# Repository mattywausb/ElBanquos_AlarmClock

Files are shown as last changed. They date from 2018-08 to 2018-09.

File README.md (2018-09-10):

# ElBanquos_AlarmClock
An Arduino based radio alarm clock with a unique display method and an efficient user interface
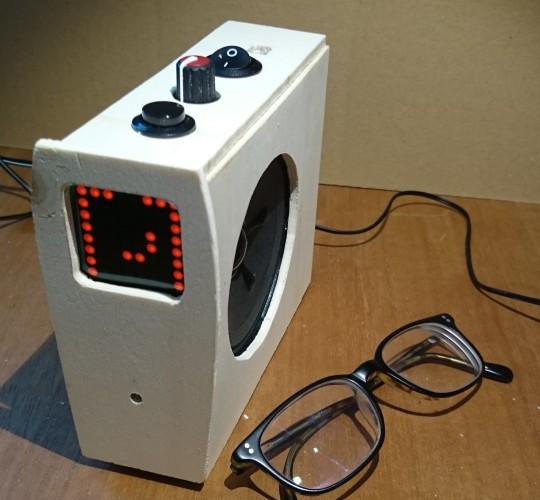
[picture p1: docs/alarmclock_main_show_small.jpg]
Overview Picture The clock and my glasses


* [Bedienungsanleitung (German Manual)](https://mattywausb.github.io/ElBanquos_AlarmClock/docs/manual-de.html)
* [Manual](https://mattywausb.github.io/ElBanquos_AlarmClock/docs/manual-en.html)

# Introduction
Actual alarm clocks are often not designed very well, because they try to be cheap and very multifunctional.
I want to create an alarm clock, that is optimized by enhanceing the essential features an reducing all gimmicks not necessary for the job.

Essential functions of a radio alarm clock
* show the actual time (in a good adapted brightness)
* Play radio to wake me up (fading it smothly in)
* efficient and reliable change of alarm time
* ensure correct volume of sound (minimize risk of silent alarm due to bad volume controller)
* Get correct time through available broadcast services (RDS is best, since we need a radio module anyway)
* Snooze function
* "Hard to Kill" alarm off procedure (Procedure needs more then just hitting a button)
* Switch bewteen alarm mode and non alarm mode
* stop bothering after (1?) Hour

Personal essential feature
* show time in a pattern, a short sighted person still can recognize over 2 meters 
* Nap function (Wake me up after a defined interval)

Nice to have functions
* Sleep function - Play Radio on demand for a defined time and fade it out smoothly

Further extentions
* Dim up light to simulate sunrise before starting the radio

Unecessary function
* Play radio for endless time
* Change radio stations (I always wake up with the same)
* Show Radio Station name
* shot weather and other data etc.

# Repository content
In the repository you will find all necessary code and diagrams to build the clock by yourself
* Arduino sketch including
** Display programming
** Encoder reading
** RDS Data cleansing procedure
** "EEPROM Database" class for easy storing data on EEPROM
* Fritzing circuit plan (not full PCB layout, since I just build on prototype boards)
** Also provided as png export
* Manuals and design approach
* Rough skecth to build a housing
* [List of Parts](https://mattywausb.github.io/ElBanquos_AlarmClock/docs/listofparts.html)

# Tools you need
* Arduino IDE
* Frizing
* inkscape (or some other svg tool to read the building sketches)

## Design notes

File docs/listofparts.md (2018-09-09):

This is hopefully the list of all parts I needed. For better orientation it is devided over multimple subassemblies

# Power supply and basic elements
* 9V regulated power plug (Main Power input)
* prototyping PCB board
* Wires, double wires and ribbon cables
* 2 port contact terminal or 9v power socket

# core processing elements 
(Needed to test the software)
* arduino nano
* SI 470x Radio Module
* 8x8 LED Matrix board with max7219 driver
* 5 wire connector cable
* photodiode
* 10 k Resistor
* encoder switch with button function
* button (Easy to hit)
* switch with tight movement
* cheap earphone (need just the cable with the plug as antenna an input to the amplifier)

# Audio amplifier 
(Needed to hear anything without earphone)
* lm7805 voltage regulator
* 100nf capacitor
* 470nf capacitor
* lm386 operations amplifier
* 20k potentionmeter
* 100nF capacitor
* 2x 100uF capacitor
* Speaker (8cm diameter)
* 2 port Contact terminal

# Housing 
(Needed, so you dont fall into your electronics at night)
* plywood 4-6mm of your favourite kind
* green light filter (to reduce overall brightness of the red led)
* Anything to hold everythin together (Scews, nuts, glue etc)

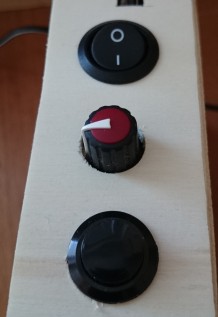
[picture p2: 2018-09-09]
docs/Buttons.jpg

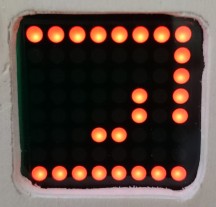
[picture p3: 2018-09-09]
docs/time04-30.jpg

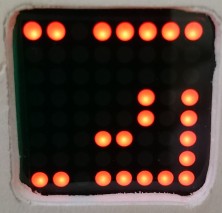
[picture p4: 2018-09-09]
docs/time02-30-almoff.jpg

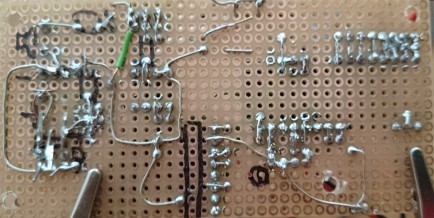
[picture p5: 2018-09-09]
docs/pcb_bottom_side.jpg

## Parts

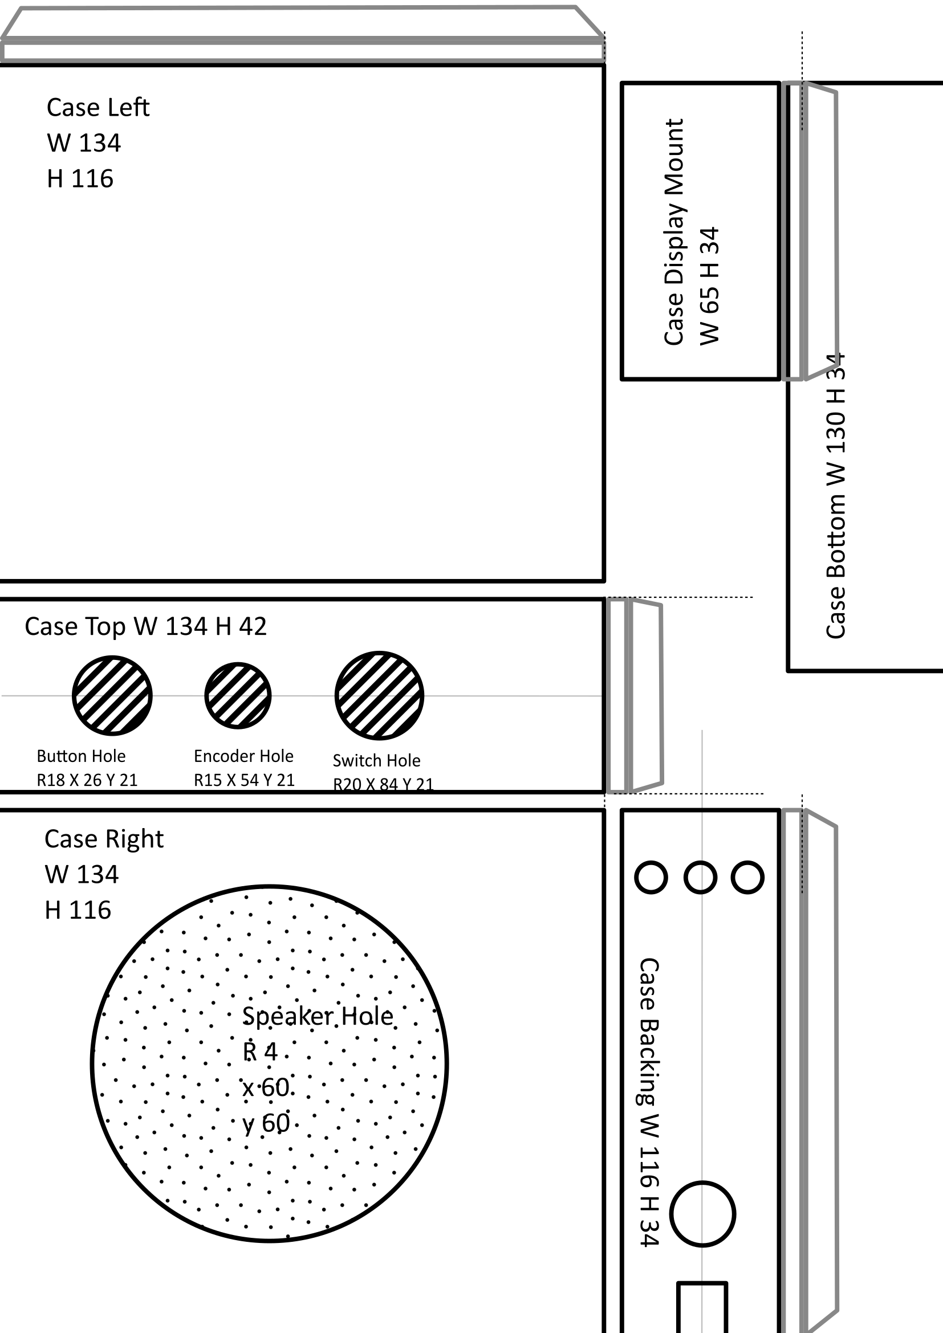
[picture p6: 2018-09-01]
docs/case parts cutting layout.png

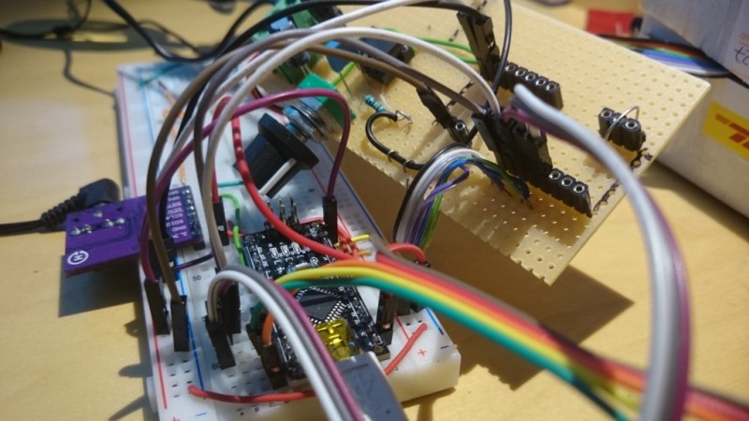
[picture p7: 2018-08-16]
docs/Digital_and_analog_parts.JPG

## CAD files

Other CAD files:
blender/model_mk2.blend

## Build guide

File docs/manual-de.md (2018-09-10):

# El Banquos Radiowecker - Bedienungsanleitung

Mangels eines ausgereiften Produktes in den hiesigen Elektronikmärkten habe ich mir einen eigenen Radiowecker gebaut,
der folgende Eigenschaften in sich vereint:

* Leicht einstellbare Weckzeit (Vor- und Zurückstellbar)
* "Einblenden" der Radiolautstärke zur Weckzeit (statt brachialem "Radio an")
* Eine Anzeige die ich auch ohne Brille(Kurzsichtig) ablesen kann, aber nicht gleich riesig ist
* "entspannte" Zeitanzeige (Ich brauche es nicht auf die Minute genau) 
* Anzeige ist nur so hell, wie gerade nötig und nicht mit geschlossenen Augen warnehmbar
* Stellt sich selbst mittels der im Radiosignal verfügbare Zeitinformation (RDS)
* Nickerchenfunktion (Radio an nach definiertem Interval (z.B. 20 Min für PowerNap)
* Deaktivieren des Alarms kann nicht aus Versehen passieren
* Sender und Lautstärke können nicht aus Versehen verstellt werden

# Bestandteile des Weckers
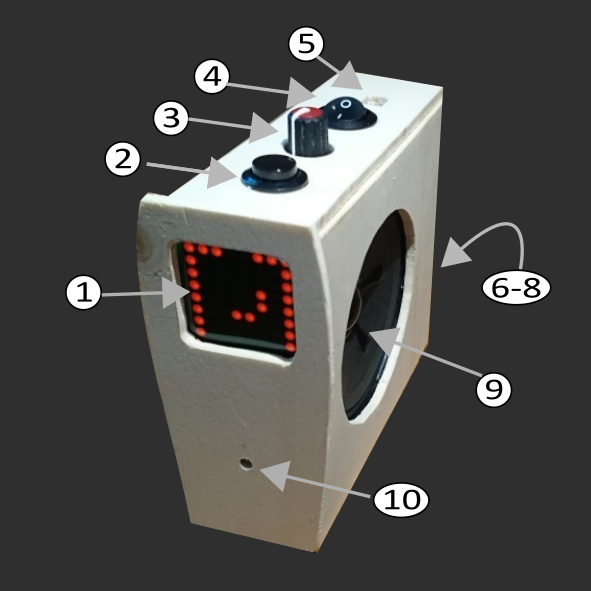
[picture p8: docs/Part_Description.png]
Bild Teilebezeichnung

1. 8x8 LED Punkmatrix Display zur Anzeige aller Informationen
2. Schlummer Taste
3. Drehregler und Taste Einstellung und Bestätigung verschiedener Funktionen
4. Weckfunktionschalter 
5. USB Port des Arduino für Softwareupdates
6. "Wurfantenne"
7. Lauststärkeregler
8. Kabelausgang zum Netzteil
9. Lautsprecher
10. Lichtsensor

# Inbetriebnahme und Schnellstart
1. Wecker an das Stromnetz anschließen -> Auf dem Display erscheit kurz ein "Bestätigungssymbol" und danach die "Zeitsuchanzeige". Der Wecker 
wartet nun auf Zeitinformationen im Radiosignal. Da diese nur 1 mal pro Minute gesendet werden und der Wecker
außerdem mindestens auf 10 plausible Werte waret, wird dieser Vorgang mindestens 10 Minuten dauern. Trotzdem kann jetzt schon die Weckzeit eingestellt werden
2. Einstellen der Weckzeit einleiten durch einmaliges Drücken auf den Drehschalter
3. Drehregler vor- oder zurückdrehen bis die gewünschte Weckzeit angezeigt wird (siehe gleich, lesen der Zeitanzeige)
4. Drehregler drücken um die gewählte Zeit als Weckzeit zu speichern -  Auf dem Display erscheit kurz ein "Bestätigungssymbol" 
und danach die Zeitanzeige bzw. die Zeitsuchanzeige
5. Weckfunktionschalter auf 1 stellen  -> In der Zeitanzeige wird der Status entsprechend angezeigt.

Der Wecker schaltete sich nun zu der gesetzten Uhrzeit ein.
* Um den Alarm für 10 Minuten zu pausieren, Schlummer Taste drücken -> Radio geht aus, Im Display blinken zwei Punkte. Das Radio schaltet sich nach 10 Minuten wieder an
* Um den Alarm abzustellen, den Drehregler drehen-> Auf dem Display wird mit der Drehbewegung ein Quadrat gezeichnet. 
Hat man weit geng gedreht um das Quadrat zu komplettieren, wird der Alarm beendet
* Um zu verhindern, das der Alarm am nächsten Tag erneut aktiv wird, muss der Alarmschalter auf 0 gestellt werden.

Hinweis: Ein aktiver Alarm wird durch abschalten des Weckfunktionschalters nicht beendet. Dazu ist die beschriebene Prozedur  mit dem Drehregler notnwedig
Alternativ schaltet sich das Radio nach 1 Stunde automatisch ab.

# Die Uhrzeitanzeige
Die Zeitanzeige wurde so gestaltet, dass sie in der Nacht auch von einem kurzsichtigen Menschen ohne Brille mit moderatem Abstand gelesen werden kann. 
Sie ist deshalb mit einfachen Linienmustern konzipiert, die für alle Zeiteinheiten gut differenzierbar sind. 

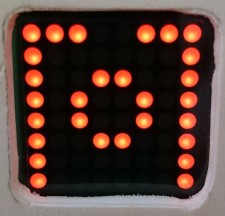
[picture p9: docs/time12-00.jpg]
time1200 12:00 Uhr


Die Anzeige teilt sich in zwei Elemente:
* Stundenrahmen (mit einer 1 Stunden und 3 Stunden Lücke)
* Viertelstundenkreis
Da die Zeit insgesamt mit einer Genauigkeit von nur 15 Minuten angezeigt wird, ist sie gegenüber der präzisen Zeit um 5 Minuten
vorversetzt, d.h. die volle Stunde wird 5 Minuten vor dem erreichen der vollen Stunde angezeigt. 
Der gleiche Versatz für alle weiteren Abschnitte der Stunde. (Dieser Verstatz gilt nur für die Echtzeitanzeige. Die Einstellung der Alarmzeit hat eine exakte Anzeige)
## Der Stundenrahmen
Der Stundenrahmen wird am äußeren Rand des Displays angezeigt. Eine kleine Lücke aus 2 Punkten zeigt die aktuelle Stunde an, analog wie bei einer Zeigeruhr (12 Uhr oben mittig, 3 uhr rechts mittig usw).

Ab 20 Minuten vor der Folgestunde rückt diese Lücke um ein Punkt vor, um die relative Nähe
zur kommenden Stunde anzuzeigen. 

Die Rahmenkante gegnüber der Stundenlücke wird komplett offen gelassen (große Lücke). Dadurch ist eine sehr grobe Einschätzung der Zeit ohne Erkennen der kleinen Lücke möglich. Gerade die allgemein "weckkrittischen" Stunden 5-7 Uhr sind damit gut von den davor liegenden Stunden 11-1 und 2-4 unterscheidbar.

Solange der Alarm über den Schalter **abgeschaltet** ist, wird dies durch **zwei Lücken** in den "seitlichen" Rahmenkanten erkennbar gemacht.
## Viertelstundenkreis
In der Mitte des Displays wird der Fortschritt innerhalb einer Stunde in 15 Minutenschritten angezeigt.
* -5 Minuten bis + 5 Minuten zur vollen Stunde: Voller kreis
* 5 Minuten- 10 Minuten: keine Markierung in der Mitte
* 10 - 25 Minuten: 2 Pixel rechts der Mitte
* 25-40 Minuten: zusätzlich 2 Pixel unterhalb der Mitte
* 40-55 Minuten: zusätzlich 2 Pixel links der Mitte
## Beispiele

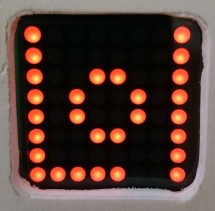
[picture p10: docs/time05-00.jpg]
display 05:00 Uhr
| 5:00 Uhr
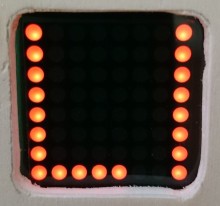
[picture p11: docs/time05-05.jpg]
display 05:05 Uhr
| 5:05 Uhr
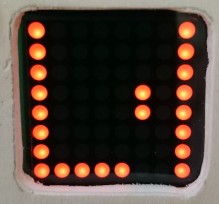
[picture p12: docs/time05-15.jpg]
display 05:15 Uhr
| 5:15 Uhr
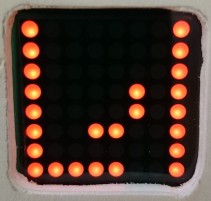
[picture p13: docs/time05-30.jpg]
display 05:30 Uhr
| 5:30 Uhr
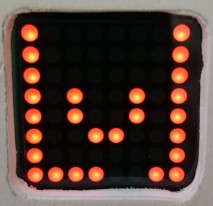
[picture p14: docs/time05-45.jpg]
display 05:45 Uhr
| 5:45 Uhr
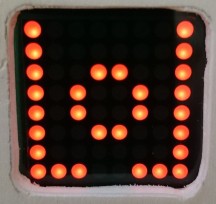
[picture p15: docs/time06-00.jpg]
display 06:00 Uhr
| 6:00 Uhr

# Die Weckzeitanzeige
Die Weckzeitanzeige ist ähnlich wie die Uhrzeitanzeige abzulesen. Es gibt folgende Unterschiede:
* Minuten werden in mit einem kleinen Quadreat(4x4) in der Mitte des Displays dargestellt. Jeder Punkt des Quardrates steht für 5 Minuten. Der volle Kreis steht für die volle Stunde.
* Uhrzeiten am Nachmittag und Abend  (12-23 Uhr) werden durch einen ausgefüllten Mittelpunkt der Anzeige kenntlich gemacht.
* Die sonst offene Kante des Stundenrahmens ist geschlossen (Anzeige der Weckzeit) oder blinkt (Einstellung der Weckzeit)
* Die angezeigte Zeit entspricht exakt dem Wert, der gerade gewählt wurde.
## Beispiele
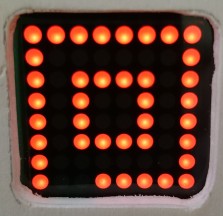
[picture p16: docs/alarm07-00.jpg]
display 07:00 Uhr
| 7:00 Uhr
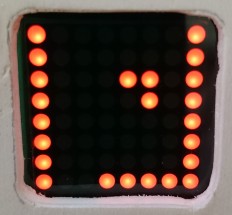
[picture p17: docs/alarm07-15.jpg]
display 07:15 Uhr
| 7:15 Uhr
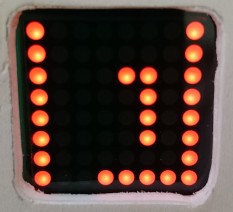
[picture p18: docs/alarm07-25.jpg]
display 07:25 Uhr
| 7:25 Uhr
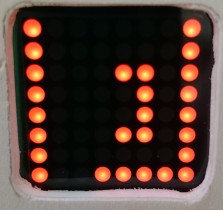
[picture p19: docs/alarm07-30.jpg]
display 07:30 Uhr
| 7:30 Uhr

# Bedienung

## Weckzeit anzeigen
Wenn sich das der Wecker im Ruhezustand befindet (Anzeige der Uhrzeit, keine laufender Alarm) kann man sich die eingestellte Weckzeit wie folgt anzeigen lassen:
1. Drehregler drehen -> Die Weckzeit wird angezeigt, nach einer kurzen Wartezeit springt die anzeige selbständig zurück auf die Uhrzeit

Alternativ kann mit der Schlummer Taste unverzüglich auf die Uhrzeit zurückgeschaltet werden

## Weckzeit stellen
Wenn sich der Wecker im Ruhezustand befinden (Anzeige der Uhrzeit oder Weckzeit, kein laufender Alarm) kann die Weckzeit wie folgt eingestellt werden:
1. Drehregler drücken -> Die Weckzeit wird angezeigt, wobei die offene Kante des Stundenrahmens blinkt
2. Drehregler vor oder zurückdrehen bis die gewünschte Weckzeit angezeigt wird 
3. Drehregler drücken oder 10 Sekunden keine Bedienung vornehmen um die gewählte Zeit als Weckzeit festzulegen-->  Auf dem Display erscheint kurz ein "Bestätigungssymbol" und danach die Zeitanzeige bzw. die Zeitsuchanzeige

Alternativ kann mit dem Schlummer Taste die Änderung der Weckzeit abgebrochen werden.

## Weckfunktion ein/ausshalten
Die grundsätzliche Aktivierung der Weckfunktion erfolgt mit dem Weckfunktionschalter. Damit der Alarm bei Erreichen der Weckzeit aktiviert wird, muss dieser Schalter auf "1" gestellt sein. Ist er auf "0" gestellt und der Alarm damit deaktiviert, wird dies durch zwei kleine Lücken in den seitlichen Kanten des Stundenrahmens im Display angezeigt.
Alarm an: time1200 12:00 Uhr Alarm an
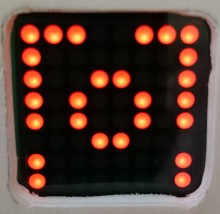
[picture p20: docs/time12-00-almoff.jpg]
time1200 12:00 Uhr Alarm aus
Alarm aus: 

**Hinweis:** Ein laufender Alarm wird durch das Auschalten nicht beendet.
Die "Nickerchen" Funktion arbeitet unabhängig von der Position des Alarmschalters.

## Alarm pausieren ("Schlummer")
Wenn das Radio aufgrund des erreichens der Alarmzeit eingeschaltet wurde, kann man den Alarm pausieren:
1. Schlummer Taste betätigen -> Das Radio wird abgeschaltet und nach 10 Minuten erneut aktiviert. Während der "Schlummerphase" blinken zwei Punkte in der offenen Kante der Uhrzeitanzeige.

## Aktuellen Alarm beenden
Um einen laufenden  oder pausierten Alarm zu beenden:
1. Drehregler drehen-> Auf dem Display erscheint Quadrat mit einem Mittelpunkt
2. Drehregler weiter drehen bis das Quadrat verschwunden ist -> der Alarm wird beendet
alm of procedure display Anzeige zum ausschalten des laufenden Alarms

## Nickerchenfunktion
Für ein Nickerchen, kann der Wecker unabhängig von der Weckzeit auf ein Intervall eingestellt werden, nach dem er dann die Weckfunktion aktiviert.
1. Schlummer Taste drücken -> Auf dem Display erscheint ein  "Minutenquadrat", voreingestellt auf 20 Minuten(=4 Punkte) (Be schon laufender Nickerchenfunktion wird die verbleibenden Restzeit angezeigt)
2. Mit dem Drehregler kann die Dauer in 5 Minutenschritten zwischen 0 und 120 Minuten(großes komplettes Quadrat) geändert werden 
3. Mit drücken auf den Drehregler (oder aber nach 10 Sekunden ohne Bedienhandlung) wird die gewählte Dauer bestätigen -> Bestätigtungshaken erscheint und danach die Uhrzeit wobei zwei Punkte in der offenen Kante des Stundenrahmens blinken

Der Wecker alarmiert nach Ablauf der eingestellten Zeit.

## Nickerchenfunktion ausschalten
Die Nickerchenfunktion ist im Grunde identisch mit der Schlummerfunktion. Entsprend wird sie auch genauso abgeschaltet 
1. Drehregler drehen-> Auf dem Display erscheint mit der Drehbewegung ein Quadrat 
2. Drehregler weiter drehen bis das Quadrat verschwunden ist ->  die Nickerchenfunktion wird abgeschaltet (der Alarm beendet)

## Einschlaffunktion / Radio an
Über die Schlaffunktion kann das Radio spontan für eine definierte Zeit eingeschaltet werden.
1. Schlummer Taste drücken --> Auf dem Display erscheint ein  "Minutenquadrat", voreingestellt auf 20 Minuten für ein Nickerchen
2. Mit dem Drehregler die Dauer verringern und über den Nullpunkt drehen-> das Radio schaltet sich ein.
3. Durch Weiterdrehen kann die Einschaltdauer in 5 Minutenschritten geändert werden 
4. Mit Drücken auf den Drehregler die gewählte Dauer bestätigen -> Das Radio wird sich nach Ablaufen der Dauer abschalten

Alternativ: Wird nach der Anpassung der Zeit keine weitere Bedienung vorgenommen, wird die angezeigte Zeit als Laufzeit übernommen

## Einschlaffunktion / Radio abschalten
Wenn das Radio über die Schlaffunktion aktiviert wurde, kann es wie folgt abgeschaltet werden:
1. Schlummer Taste drücken -> Auf dem Display erscheint das  "Minutenquadrat, mit der Restzeit der Schlaffunktion
2. Schlummer Taste drücken -> die Schlaffunktion wird abgeschaltet

Alternativ kann die Zeitdauer mit dem Drehregler auch wieder angepasst werden.

# Zeitsuchanzeige
Die Zeitinformation im RDS Signal ist störanfällig und bedarf einer längeren Prüfung bevor sie vertrauenswürdig ist. Die Zeitsuchanzeige wird angezeigt, solange der Wecker nach dem Einschalten keine zuverlässige Uhrzeitinformation besitzt.
Sie besteht aus folgenden Elementen:
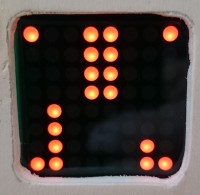
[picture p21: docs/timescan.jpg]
timescan Zeitsuchanzeige

* Linker Balken von unten nach oben: Empfangsstärke des laufenden Senders 
* Mittlerer Balken von oben nach unten: Vertrauen in den aktuell empfangenden RDS Wert (Wenn dieser Balken den unteren Displayrand erreicht, wurden genügen Informationen gesammelt um die Uhrzeit zu übernehmen) 
* Rechter Balken von unten nach oben: Vertrauen in die aktive Uhrzeit

Die Uhr übernimmt die aktuelle  RDS Uhrzeit nur dann, wenn sie das gleiche oder bessere Vertrauen in die RDS zeit als in die laufende Uhrzeit hat. Zu Sommer/Winterzeitumstellung werden 20 korrekte Messungen benötigt, bis die neue Uhrzeit in das System übernommen wird. Eine Weckzeit zwischen 3:00 und 3:20 in der Winterzeitumstellung wird daher nicht korrekt erkannt.

# Verhalten bei einem Neustart
Ein Neustart der Uhr erfolgt
* Nach einem Stromausfall
* bei internen Reboot aufgrund eines nicht behebbaren Fehlers

Die Weckzeit sowie ein laufender Alarm oder Nickermodus werden von der Uhr im Festwertspeicher gemerkt und beim Neustart wieder ausgelesen. Sowie die Uhr wieder aktiv ist nutzt sie diese Information um ggf. unverzüglich einen Alarm zu aktivieren wenn

* (noch zu implementieren) Der Schlummermodus war aktiv
* Eine "Nickerchenzeit" gesetzt war
* Zeit über RDS als korrekt bewertet wurde und die eingestellte Weckzeit weniger als 60 Minuten her ist 

# Sender Preset auswählen
Das Radio hat 4 Senderpresets, die auch bei der Suche der RDS Zeit durchsucht werden. Die Fequenzen sind direkt im Code hintelegt. Das Preset, das zum Wecken benutzt wird, kann wie folgt ausgewählt werde,
1. Schlummer Taste drücken -> Auf dem Display erscheint das  "Minutenquadrat, mit der Restzeit der Schlaffunktion oder Nickerchenfunktion"
2. Mit dem Drehregler die Zeit über den größten Wert hinaus drehen bis ein "P" auf dem Display erscheint.
3. Drehregler drücken-> Presetauswahlmodus wird gestartet
4. Mit dem Drehregler das gewünschte Preset auswählen

Zusatz: Mit der Schlummer Taste kann das Radio in diesem Modus ein und ausgeschaltet werden.

# Diagnosefunktion(Trace)
Um die Funktionstüchtigkeit des Weckers zu beurteilen, können über die Trace Funktion interne Werte der Uhr abgerufen werden.
1. Schlummer Taste drücken -> Auf dem Display erscheint das  "Minutenquadrat, mit der Restzeit der Schlaffunktion oder Nickerchenfunktion"
2. Mit dem Drehregler die Zeit über den größen Wert hinaus drehen bis ein "T" auf dem Display erscheint.
3. Drehregler drücken-> Diagnosemodus wird gestartet
4. Mit den Drehregler die gewünscht Diagnoseseite wählen
     1. Stundenwert der Uhr ( - -  wenn nocht keine Uhrzeit verfügbar ist)
     2. Minutenwert der Uhr ( - -  wenn nocht keine Uhrzeit verfügbar ist)
     3. Zeitsuchanzeige
     4. Empfangsstärke 
     5. 10er und 1 Ziffer der Frequenz des aktiven Senders
     6. Nachkommastellen der Frequenz des aktiven Senders
     7. Anzeige der Systemlaufzeit in "Binary Coded Decimal" (Zeile 8 Sekunden, Zeile 7 Minuten, Zeile 6 Stunden, Zeile 5 Tage). Die Systemlaufzeit beginnt nach ca. 50 Tagen von vorne bzw. nach jedem "Reboot".
     
Als weitere Diagnoseinformation Möglichkeit dient die LED auf dem Arduino Board, die bei geöffnetem Geäuse sichtbar wird. Diese wird synchron zum Radio ein und ausgeschaltet. Sollte also die LED leuchten, aber kein Ton zu hören sein, wären Laustärkeregler, Verstärker und Lautsprecher auf lose Kontakte zu prüfen.

# Demo Funktion
Um die Zeitanzeige besser kennenzulernen kann die Demofunktion genutzt werden:
1. Schlummer Taste drücken -> Auf dem Display erscheint das  "Minutenquadrat, mit der Restzeit der Schlaffunktion oder Nickerchenfunktion"
2. Mit dem Drehregler die Zeit über den größen Wert hinaus drehen bis ein "D" auf dem Display erscheint.
3. Drehregler drücken-> Demo Funktion wird gestartet und eine "Demo" Uhrzeit angezeigt

Die dem Drehregler kann die Uhrzeit geändert werden. Nach einer kurzen Zeit schaltet die Zeit auch selbstängig schnell vorwärts.
Wird länger keine Bedienung vorgenommen, wird wieder die Normalzeit angezeigt.

Mit der Schlummertaste kann die Demo Funktion aktiv beendet werden.

# Hintergründe für das Design
## Anzeige
Die übliche Anzeige mit Ziffern, hat den Nachteil, dass einige Zahlen nur schwer unterscheidbar sind, wenn man nicht über die komplette
Sehschärfe verfügt. So ist eine 5 schwer von eine 6 zu unterscheiden (was am Morgen den Unterschied zwischen Weiterschlafen und Panik 
ausmachen kann)
Analoge Uhrenziffernblätter sind diesbezüglich einfacher, haben aber immer noch das Problem der eindeutigen Orientierung. Eine leichte 
Kopfneigung kann aus einer 5:20  eine 4:15 machen (oder umgekehrt).
Das jetzige Konzept löst beide Probleme:
* Aufgrund der Quadratischen Form ist für eine Lageverwechslung eine Fehleinschätzung von 45 Grad notwendig
* Die Anzeige der Viertelstunden ist bietet von 15-35 Minuten eine zusätzliche Richtungsorientierung

Beim Ausprobieren verschiedener Darstellungen hat sich außerdem gezeigt, dass es unumgänglich ist, dem Nutzer immer eine Orientierung bzgl
der Gesamtgröße des Disyplays zu geben. Auch hat sich gezeigt, dass eine Unterbrechung von Linien immer 
zu Ableseproblemen führt. Daraus ergab sich am Ende der Ansatz mit dem Rahmen.

## Anordnung der Bedienelemente
* Die Hauptbedienelmente liegen oben und werden vertikal betätigt, damit der Wecker beim Betätigen nicht aus versehen verschoben wird bzw. mit einer zweiten Hand festgehalten werden muss
* der Lauststärkeregler liegt hinten, da er nach der optimalen Einstellung nicht aus Versehen verstellt werden soll
* Die Hauptbedienelmente liegen hintereinander, entsprechend ihrer Priorität der Nutzung beim Wecken. Schlummer zuerst, Alarmzeit einstellen und Alarm beenden als nächstes, Alarm aus/an als drittes

## Bedienungsabfolge
Die Bedienabfolge ist so gestaltet, dass die Bedienung beim zu Bett gehen(auch für ein Nickerchen) so wenig Geräusche wie möglich verursacht um "akustische Trigger", die den Körper wieder aufwecken, zu vermeiden.
Akustische Trigger sind: Drücken des Drehreglers, aktivierung des Radios. 

* Bedienungen ohne Geräusche: Alarmzeit anschauen, Nickerchenzeit setzen, Alarm pausieren, Alarm beenden
, Sender prüfen/ändern
* Bedienung mit 1 Klick: Alarmzeit ändern,Radiosender wählen

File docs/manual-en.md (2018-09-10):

# El Banquos Alarm Clock - Manual

Since I could not find a suitable alarm clock in the stores I decided to build my own with the following features:
* easy adjustable alarm time
* fading volume when alarm starts
* compact display design that is readable by shortsighted person (me)
* adjusted and display brightness that can not be noticed with closed eyes
* self adjusting time by using radio data signal
* nap function for taking a shot nap at daytime independendtly from alarm setting
* deactivating alarm cannot be an accident
* Radio station and Volume cannot be changed by accident
# Elements of the clock
Bild Teilebezeichnung

1. 8x8 LED Dot Matrix display
2. Snooze Button
3. Selection Knob
4. Wakeup function switch
5. USB port of the Arduino for Softwareupdates
6. Antenna cable
7. Volume Control
8. Cable to power supply
9. Speaker
10. Light sensor

# Quickstart
1. Plug in the Power Supply -> The Display should show a short "Acknowledge" Symbol and the clock will start with the rds data scanning display (more details on this later). Since rds time data is usially send only once a minute and the clock needs at least 10 consecutive plausible time telegrams, this will take at least 10 Minutes and will become  longer if the signal is weak or disturbed. Nevertheless it is possible to set the alarm time without having the correct time.
2. Start alarm time selection by pushing the selection knob(3) 
3. Turn the selection knob(3) to adjust the alarm time (how to read the display, see next chapter)
4. Push selection knob(3) to store the selected alarm time -> The Display shows a short "Acknowledge" Symbol 
5. Check that the Wakeup function switch (4) is set to 1

The alarm clock will play the radio at the given time.
* to pause the alarm for 10 minutes presse the Snooze Button(1) -> radio will switch of and indicate the snooze mode with two blinking dots.
* to stop the alarm turn the knob (3)->The display shows an outer and inner square. The outer square that starts disappearing while turning the knob. When the outer square is vanished, the alarm is stopped.

If there is no interaction for 60 minutes, the radio will stop playing by itself.

* to switch off the wake up function for the upcoming days, set the wakup function switch(4) to 0 

**Notice:** An active alarm or snoozed alarm will *not be stopped by switching the wakup function switch*. Only the "turning knob procedure" will stop the current alarm.

# Time display
The time display is designed to be even readable for moderate shortsighted persons when lying with the clock on the nightstand (1-2m). Since numerc digits (especially the crutial 5 and 6 in the morning) are hard to tell from each other the concept uses a pure graphical approach

time1200 12:00 Uhr

The display consists of two elements:
* The hour frame (with a 1 hour indication gap and a 3 hour indication "counter gap")
* The quater hour circle
Since healthy waking up should be done in a more relaxed manner the time resolution is only 15 minutes and the display shows the current time five minutes in advance (e.g. it shows the 12:00 pattern already at 11:55). This offset is only used for the time display. Selection of alarm time and start of the alarm is at the precise moment. 

## The hour frame
The hour frame is displayed using the border of the matrix display. A small gap of 2 pixels indicates the current hour at the same position as known on analog watches. (12 at top, 3 at the mid of right side, 6 at bottom, 9 at the mid of the left side)
20 Minutes befor the upcoming next hour, the gap will move one pixel forward to indicate the progress.

Only the frame line with the gap an its neighbours are shown. Opposite line to the gap is not lit. So by only reading the orientation of the three lit lines of the frame it is possibile to distinguish the 3 hour blocks 11-1, 2-4, 5-7, 8-11. This provides roug readablity for even more distance.

### Wakup function switch indicator
When the wakup function is *switched off*, this will be indicated by placing a *one pixel gap* in each of the side lines. 

## Quater hour circle
The middle of the display is used to indicate the progess of time in one hour. This is done as follows:
* -5 minutes to 5 minutes to the whole hour: complete circle
* 5 minutes to 10 minutes: no marking in the middle
* 10 - 25 minutes: 2 Pixels right to the middle
* 25-40 minutes: additional 2 Pixel below the middle
* 40-55 minutes: additional 2 Pixel left to the middle
## Examples

display 05:00| 5:00 
display 05:05| 5:05 
display 05:15| 5:15 
display 05:30| 5:30 
display 05:45| 5:45 
display 06:00| 6:00 |

It takes 2 or 3 days to get used to it but then gets very intuitive.

# Alarm time display
The alarm time display is nearly similar to the time display with the following modifications:
* Minutes are displayed as 5 minutes per pixel in a inner square
* Hours between noon and midnoght (12-23 aka. p.m.) are indicated by lighint the for middle pixels in the display
* All four sides of the outer square are lit or flashing
* the time shown is the time chosen (no 5 minute offset)

## Examples

display 07:00| 7:00 
display 07:15| 7:15 
display 07:25| 7:25 
display 07:30| 7:30 

# Operations
A lot of "trivial"operations are not translated yet. Instead I focussed the special ones.

## Nap function
For taking a shot nap, you can set up an interval after the alarm will start. This function works independently of the normal alarm time and the wake up switch. To activate the nap function:
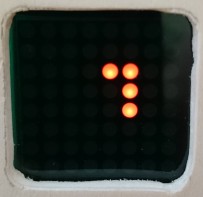
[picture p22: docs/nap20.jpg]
nap Nap display 20 min

1. press snooze button(2) -> The display will show only an "Minute display" starting with 4 Pixel (20 minutes with 5 Minutes per pixel)
2. Turn the knob(3) to adjust the length of the interval in 5 minute steps. When turning over 1 hour, a second square will be drawn until you reach the maximum of 2 hours
3. Press the knob(3) (or leave the clock alone for 10 seconds) to activate the function -> after showing an acknowledgement the display will switch back to the normal Clock display but will additionalli  flash two pixels  to indicate the active nap function

The the time is up, the clock will start the normal alarm procedure (with snooze function and switch off procedure).

## Cancel nap function before alarm
Cancling the nap function is done with the alarm off procedure (since it is internally just a user defined snooze mode).
1. turn the knob (3)->The display shows an outer and inner square. The outer square starts disappearing while turning the knob further. When the outer square is vanished, the nap function is stopped.

----
# ------- To be translated later:-----------
----

# Bedienung

## Weckzeit anzeigen
Wenn sich das der Wecker im Ruhezustand befindet (Anzeige der Uhrzeit, keine laufender Alarm) kann man sich die eingestellte Weckzeit wie folgt anzeigen lassen:
1. Drehregler drehen -> Die Weckzeit wird angezeigt, nach einer kurzen Wartezeit springt die anzeige selbständig zurück auf die Uhrzeit

Alternativ kann mit der Schlummer Taste unverzüglich auf die Uhrzeit zurückgeschaltet werden

## Weckzeit stellen
Wenn sich der Wecker im Ruhezustand befinden (Anzeige der Uhrzeit oder Weckzeit, kein laufender Alarm) kann die Weckzeit wie folgt eingestellt werden:
1. Drehregler drücken -> Die Weckzeit wird angezeigt, wobei die offene Kante des Stundenrahmens blinkt
2. Drehregler vor oder zurückdrehen bis die gewünschte Weckzeit angezeigt wird 
3. Drehregler drücken oder 10 Sekunden keine Bedienung vornehmen um die gewählte Zeit als Weckzeit festzulegen-->  Auf dem Display erscheint kurz ein "Bestätigungssymbol" und danach die Zeitanzeige bzw. die Zeitsuchanzeige

Alternativ kann mit dem Schlummer Taste die Änderung der Weckzeit abgebrochen werden.

## Weckfunktion ein/ausshalten
Die grundsätzliche Aktivierung der Weckfunktion erfolgt mit dem Weckfunktionschalter. Damit der Alarm bei Erreichen der Weckzeit aktiviert wird, muss dieser Schalter auf "1" gestellt sein. Ist er auf "0" gestellt und der Alarm damit deaktiviert, wird dies durch zwei kleine Lücken in den seitlichen Kanten des Stundenrahmens im Display angezeigt.
Alarm an: time1200 12:00 Uhr Alarm an
Alarm aus: time1200 12:00 Uhr Alarm aus

**ACHTUNG:** Ein laufender Alarm wird durch das Auschalten nicht beendet.
Die "Nickerchen" Funktion arbeitet unabhängig von der Position des Alarmschalters.

## Alarm pausieren ("Schlummer")
Wenn das Radio aufgrund des erreichens der Alarmzeit eingeschaltet wurde, kann man den Alarm pausieren:
1. Schlummer Taste betätigen -> Das Radio wird abgeschaltet und nach 10 Minuten erneut aktiviert. Während der "Schlummerphase" blinken zwei Punkte in der offenen Kante der Uhrzeitanzeige.

## Aktuellen Alarm beenden
Um einen laufenden  oder pausierten Alarm zu beenden:
1. Drehregler drehen-> Auf dem Display erscheint Quadrat mit einem Mittelpunkt
2. Drehregler weiter drehen bis das Quadrat verschwunden ist -> der Alarm wird beendet
alm of procedure display Anzeige zum ausschalten des laufenden Alarms

## Einschlaffunktion / Radio an
Über die Schlaffunktion kann das Radio spontan für eine definierte Zeit eingeschaltet werden.
1. Schlummer Taste drücken --> Auf dem Display erscheint ein  "Minutenquadrat", voreingestellt auf 20 Minuten für ein Nickerchen
2. Mit dem Drehregler die Dauer verringern und über den Nullpunkt drehen-> das Radio schaltet sich ein.
3. Durch Weiterdrehen kann die Einschaltdauer in 5 Minutenschritten geändert werden 
4. Mit Drücken auf den Drehregler die gewählte Dauer bestätigen -> Das Radio wird sich nach Ablaufen der Dauer abschalten

Alternativ: Wird nach der Anpassung der Zeit keine weitere Bedienung vorgenommen, wird die angezeigte Zeit als Laufzeit übernommen

## Einschlaffunktion / Radio abschalten
Wenn das Radio über die Schlaffunktion aktiviert wurde, kann es wie folgt abgeschaltet werden:
1. Schlummer Taste drücken -> Auf dem Display erscheint das  "Minutenquadrat, mit der Restzeit der Schlaffunktion
2. Schlummer Taste drücken -> die Schlaffunktion wird abgeschaltet

# Zeitsuchanzeige
Die Zeitinformation im RDS Signal ist störanfällig und bedarf einer längeren Prüfung bevor sie vertrauenswürdig ist. Die Zeitsuchanzeige wird angezeigt, solange der Wecker nach dem Einschalten keine zuverlässige Uhrzeitinformation besitzt.
Sie besteht aus folgenden Elementen:
timescan Zeitsuchanzeige
* Linker Balken von unten nach oben: Empfangsstärke des laufenden Senders 
* Mittlerer Balken von oben nach unten: Vertrauen in den aktuell empfangenden RDS Wert (Wenn dieser Balken den unteren Displayrand erreicht, wurden genügen Informationen gesammelt um die Uhrzeit zu übernehmen) 
* Rechter Balken von unten nach oben: Vertrauen in die aktive Uhrzeit

Die Uhr übernimmt die aktuelle  RDS Uhrzeit nur dann, wenn sie das gleiche oder bessere Vertrauen in die RDS zeit als in die laufende Uhrzeit hat. Zu Sommer/Winterzeitumstellung werden 20 korrekte Messungen benötigt, bis die neue Uhrzeit in das System übernommen wird. Eine Weckzeit zwischen 3:00 und 3:20 in der Winterzeitumstellung wird daher nicht korrekt erkannt.

# Verhalten bei einem Neustart
Ein Neustart der Uhr erfolgt
* Nach einem Stromausfall
* bei internen Reboot aufgrund eines nicht behebbaren Fehlers

Die Weckzeit sowie ein laufender Alarm oder Nickermodus werden von der Uhr im Festwertspeicher gemerkt und beim Neustart wieder ausgelesen. Sowie die Uhr wieder aktiv ist nutzt sie diese Information um ggf. unverzüglich einen Alarm zu aktivieren wenn

* (noch zu implementieren) Der Schlummermodus war aktiv
* Eine "Nickerchenzeit" gesetzt war
* Zeit über RDS als korrekt bewertet wurde und die eingestellte Weckzeit weniger als 60 Minuten her ist 

# Sender Preset auswählen
Das Radio hat 4 Senderpresets, die auch bei der Suche der RDS Zeit durchsucht werden. Die Fequenzen sind direkt im Code hintelegt. Das Preset, das zum Wecken benutzt wird, kann wie folgt ausgewählt werde,
1. Schlummer Taste drücken -> Auf dem Display erscheint das  "Minutenquadrat, mit der Restzeit der Schlaffunktion oder Nickerchenfunktion"
2. Mit dem Drehregler die Zeit über den größten Wert hinaus drehen bis ein "P" auf dem Display erscheint.
3. Drehregler drücken-> Presetauswahlmodus wird gestartet
4. Mit dem Drehregler das gewünschte Preset auswählen

Zusatz: Mit der Schlummer Taste kann das Radio in diesem Modus ein und ausgeschaltet werden.

# Diagnosefunktion(Trace)
Um die Funktionstüchtigkeit des Weckers zu beurteilen, können über die Trace Funktion interne Werte der Uhr abgerufen werden.
1. Schlummer Taste drücken -> Auf dem Display erscheint das  "Minutenquadrat, mit der Restzeit der Schlaffunktion oder Nickerchenfunktion"
2. Mit dem Drehregler die Zeit über den größen Wert hinaus drehen bis ein "T" auf dem Display erscheint.
3. Drehregler drücken-> Diagnosemodus wird gestartet
4. Mit den Drehregler die gewünscht Diagnoseseite wählen
     1. Stundenwert der Uhr ( - -  wenn nocht keine Uhrzeit verfügbar ist)
     2. Minutenwert der Uhr ( - -  wenn nocht keine Uhrzeit verfügbar ist)
     3. Zeitsuchanzeige
     4. Empfangsstärke 
     5. 10er und 1 Ziffer der Frequenz des aktiven Senders
     6. Nachkommastellen der Frequenz des aktiven Senders
     7. Anzeige der Systemlaufzeit in "Binary Coded Decimal" (Zeile 8 Sekunden, Zeile 7 Minuten, Zeile 6 Stunden, Zeile 5 Tage). Die Systemlaufzeit beginnt nach ca. 50 Tagen von vorne bzw. nach jedem "Reboot".
     
Als weitere Diagnoseinformation Möglichkeit dient die LED auf dem Arduino Board, die bei geöffnetem Geäuse sichtbar wird. Diese wird synchron zum Radio ein und ausgeschaltet. Sollte also die LED leuchten, aber kein Ton zu hören sein, wären Laustärkeregler, Verstärker und Lautsprecher auf lose Kontakte zu prüfen.

# Demo Funktion
Um die Zeitanzeige besser kennenzulernen kann die Demofunktion genutzt werden:
1. Schlummer Taste drücken -> Auf dem Display erscheint das  "Minutenquadrat, mit der Restzeit der Schlaffunktion oder Nickerchenfunktion"
2. Mit dem Drehregler die Zeit über den größen Wert hinaus drehen bis ein "D" auf dem Display erscheint.
3. Drehregler drücken-> Demo Funktion wird gestartet und eine "Demo" Uhrzeit angezeigt

Die dem Drehregler kann die Uhrzeit geändert werden. Nach einer kurzen Zeit schaltet die Zeit auch selbstängig schnell vorwärts.
Wird länger keine Bedienung vorgenommen, wird wieder die Normalzeit angezeigt.

Mit der Schlummertaste kann die Demo Funktion aktiv beendet werden.

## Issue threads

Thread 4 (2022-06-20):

Prevent immediate RDS Station Switch on routine RDS check

mattywausb, 2022-06-20:

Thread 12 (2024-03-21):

Does not collect time signal when in nap mode

mattywausb, 2024-03-21:
Wenn rebnited and searching for time you can start the nap timer. Unfortunately the clock does not try to capture the time signal then.

Also where might be a problem l, when rebooted with immediate nap alarm. Since it also does not capture a time signal even though it shows the time capture display

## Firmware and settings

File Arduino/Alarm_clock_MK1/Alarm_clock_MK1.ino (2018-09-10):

#include "mainSettings.h"
#include "EepromDB.h"

#ifdef TRACE_ON
#define TRACE_CLOCK 
//#define DEBUG_HIGHRES_ALARMSET 1
#endif

#define REFERENCE_AGE_FOR_CHECK 30
#define REFERENCE_AGE_FOR_NOTIFY 90
#define REFERENCE_AGE_FOR_INVALID 144000

const unsigned long demo_delaytime=400;

/* Some general knowledge about time */
#define MINUTES_PER_DAY 1440
#define MILLIES_PER_DAY 86400000
#define MILLIES_PER_MINUTE 60000

/* Clock variables */

enum CLOCK_STATE {
  STATE_IDLE, // show time, check for alarms, check age of rds time 
  STATE_WAKEUP,
  STATE_STOP_PROCEDURE,
  STATE_ALARM_INFO,  // Show Alarm time
  STATE_ALARM_CHANGE,  // Change and set Alarm time
  STATE_INTERVAL_SET,  // Activate Sleep and change sleep time
  STATE_PRESET_SELECT, // Select playing station
  STATE_DEBUG,  // Show some explicit values for debugging
  STATE_DEMO  // show fast time progressing
};
CLOCK_STATE clock_state = STATE_IDLE; 

#define TIME_UNKNOWN -1
#define TRIGGER_IS_OFF -2

#define RDS_TRUST_GOOD 20         // Highest trust you can get
#define RDS_TRUST_ACCEPTABLE 10   // Minimal trust to be used
#define RDS_TRUST_CANDIDATE 4     // Number of consecutive occurences to be protected from instant replacement
#define RDS_DERIVATION_TOLERANCE 10000 // half of millisecods we accept derivation from progress calculateion
#define RDS_SCAN_COOLDOWN_TIME  750   // Milliseconds before we use the next RDS Time Telegram
//#define RDS_MAX_WAIT_TIME  300000    // after 5 Minutes (300 seconds) with no signal we change channel 
#define RDS_MAX_WAIT_TIME  150000    // after 2,5 Minutes (150 seconds) with no signal we change channel 
#define BAD_TRY_UNTIL_CHANNEL_CHANGE 14 // Number of unsuccedfull tries until we change RDS channel

#define MAX_STATION_TRUST 10

unsigned long clock_sync_time=millis();
MinutesOfDay_t clock_reference_time=TIME_UNKNOWN;
int clock_rds_trust=0;

unsigned long candidate_sync_time=millis();
MinutesOfDay_t candidate_reference_time=TIME_UNKNOWN;
int candidate_rds_trust=0;

int station_trust=MAX_STATION_TRUST;

MinutesOfDay_t clock_alarm_time[4]={0,0,0,0};
byte clock_focussed_alarmIndex=0; 
MinutesOfDay_t clock_sleep_stop_time=TRIGGER_IS_OFF;
MinutesOfDay_t clock_alarm_stop_time=TRIGGER_IS_OFF;
MinutesOfDay_t clock_interval_alarm_time=TRIGGER_IS_OFF;
byte clock_alarm_stopprocedure_progress=0;
unsigned long clock_last_wakeup_stop_millis=0;  

#define CLOCK_SETTINGS_DB_MEMORY_OFFSET 40
#define CLOCK_SETTINGS_DB_ROW_COUNT 10

EepromDB clockSettingsDB;

struct clockSettingRecord {
  MinutesOfDay_t alarm_time;
  MinutesOfDay_t interval_alarm_time;
  byte radio_preset;
}; 

/* ************************************************************
 *     Main Setup
 * ************************************************************
 */

void setup() 
{
  
  #ifdef TRACE_ON 
     char compile_signature[] = "--- START (Build: " __DATE__ " " __TIME__ ") ---";   
     Serial.begin(9600);
     Serial.println(compile_signature); 
  #endif

  struct clockSettingRecord previous_settings;
   
  output_setup();
  clockSettingsDB.setupDB(CLOCK_SETTINGS_DB_MEMORY_OFFSET, sizeof(previous_settings), CLOCK_SETTINGS_DB_ROW_COUNT);
  clock_alarm_time[0]=DEFAULT_ALARM_TIME; /* Fall back alarm */

  /* get settings from eeprom */
  if(clockSettingsDB.readRecord((byte*)(&previous_settings)))
  {
    clock_alarm_time[0]=previous_settings.alarm_time;
    clock_interval_alarm_time=previous_settings.interval_alarm_time;
    radio_setSelectedPreset(previous_settings.radio_preset);
  }

  radio_setup();
  input_setup(0, MINUTES_PER_DAY-1,15); /* Encoder Range 24 hours,stepping quater hours */

  /* If we boot with nap trigger set, we need to alarm immediatly */
  if(clock_interval_alarm_time!=TRIGGER_IS_OFF)
  {
  #ifdef TRACE_CLOCK
     Serial.println(F("!! Emergency Wakeup by interval timer detection")); 
  #endif
    
    enter_STATE_WAKEUP();
  }
  
}


/* ****************Main Loop********************************** 
 * ************************************************************
 */

void loop() { 


  /* Inputs */
  input_switches_scan_tick();
  radio_loop_tick();


  /* Sleep Timer logic */
  if(clock_getCurrentTime()==clock_sleep_stop_time) {
    radio_fadeOut();
    clock_sleep_stop_time=TRIGGER_IS_OFF;
    #ifdef TRACE_CLOCK
         Serial.println(F("SLEEP timed out"));
    #endif
  }

  /* Alarm on logic */
  if((clock_getCurrentTime()==clock_alarm_time[clock_focussed_alarmIndex] )
   &&clock_alarm_stop_time==TRIGGER_IS_OFF          // TBD: for multi alarm time, check if new alarm is running
   &&clock_state != STATE_ALARM_CHANGE
   &&clock_state != STATE_WAKEUP
   &&input_masterSwitchIsSet()
   &&(millis()-clock_last_wakeup_stop_millis>60000)  // after active stop, we must wait at least 60 seconds to perevent reactivation in case of fast reaction
   ) {
      enter_STATE_WAKEUP();
      return;
  }

  /* Interval end logic (snooze or nap) */
  if(clock_getCurrentTime()==clock_interval_alarm_time) {
    resume_STATE_WAKEUP();
    return;
  }

  /* Alarm off logic */
  if(clock_getCurrentTime()==clock_alarm_stop_time) {
    exit_STATE_WAKEUP();
    return;
  }

  /* Light Sensor logic */
  output_adjust_autobrightness(input_get_light_sensor_value());
  
  /* UI logic */
  switch (clock_state) {
    
    case STATE_IDLE:            process_STATE_IDLE(); break;
          
    case STATE_ALARM_INFO:      process_STATE_ALARM_INFO(); break;
          
    case STATE_ALARM_CHANGE:    process_STATE_ALARM_CHANGE(); break;

    case STATE_WAKEUP:          process_STATE_WAKEUP(); break;
    case STATE_STOP_PROCEDURE:  process_STATE_STOP_PROCEDURE(); break;
    
    case STATE_INTERVAL_SET:       process_STATE_INTERVAL_SET(); break;

    case STATE_PRESET_SELECT:  process_STATE_PRESET_SELECT(); break;
     
    case STATE_DEBUG:  process_STATE_DEBUG(); break;
    
    case STATE_DEMO:  process_STATE_DEMO(); break;

 /* ------------------------------------------------------------------ */  
  
    default: output_sequence_alert(); 
      enter_STATE_IDLE();
  }

  /* output */
  /* is managed by scenes and sequences call from state functions */
  /* --- no output code here ------*/

  #ifdef TRACE_CLOCK
  static MinutesOfDay_t last_traced_time;
  if( last_traced_time!=clock_getCurrentTime()) {
    last_traced_time=clock_getCurrentTime();
    Serial.print(F("Cur :"));
    Serial.print(last_traced_time/60);
    Serial.print(":");
    Serial.print(last_traced_time%60);  
    Serial.print(F(" Alm:"));
    Serial.print(clock_alarm_time[clock_focussed_alarmIndex]/60);
    Serial.print(F(":"));
    Serial.println(clock_alarm_time[clock_focussed_alarmIndex]%60);  
  }
  #endif

}

/* ************************************************************
 *     Clock functions
 * ************************************************************
 */

/*  ------------  Information ----------------- */

MinutesOfDay_t clock_getCurrentTime() {
  if(clock_rds_trust <RDS_TRUST_ACCEPTABLE) return TIME_UNKNOWN;
  return (((millis()-clock_sync_time)/60000)+clock_reference_time)%MINUTES_PER_DAY;
}

unsigned long clock_getSyncTime(){
  return clock_sync_time; 
}

MinutesOfDay_t clock_getAgeOfReference(){
  if (clock_sync_time==0) {  /* Seems we dont have any data */
    if(millis()<REFERENCE_AGE_FOR_NOTIFY) return REFERENCE_AGE_FOR_CHECK; /* Warn gracefully */
    return millis();  /* We get worried */
  }
  return (millis()-clock_sync_time)/MILLIES_PER_MINUTE;
}

int clock_getClockRDSScore()
{
  return max((clock_rds_trust*256)/ RDS_TRUST_GOOD,0);
}

int clock_getCandidateRDSScore()
{
  return max((candidate_rds_trust*256)/RDS_TRUST_ACCEPTABLE,0);
}


/* ############  Operation  ############## */

/* -------------- evaluateNewRDSTime ----------------------         
 * Evaluates the new given time 
 */

void clock_evaluateRDSTime(MinutesOfDay_t measured_time) {
static unsigned long evaluation_time;


  if( millis()-evaluation_time < RDS_SCAN_COOLDOWN_TIME     /* Dont accept values too fast  */
   || radio_getRdsTimeAge() >= RDS_SCAN_COOLDOWN_TIME  ) return;       /* Only accept fresh values in relation to cooldown  */

  evaluation_time=millis();

  
  /* change station, if we lost trust or it is not sending usable RDS timestamps */
  if( millis()-candidate_sync_time > RDS_MAX_WAIT_TIME || station_trust<=0) { 
     #ifdef TRACE_CLOCK
        Serial.println(F("RDS Timeout"));
     #endif 
     radio_switchRdsStation();  
     station_trust=MAX_STATION_TRUST;
     candidate_sync_time=evaluation_time;   
  }
  #ifdef TRACE_CLOCK
        static byte prev_second=0;
        byte cursecond=(millis()-candidate_sync_time)/10000;
        if(cursecond!=prev_second) {
          prev_second=cursecond;
          Serial.print(F("No RDS Time since:"));
          Serial.println(cursecond*10);
        }
  #endif

  /* reject rubbish */
  if(measured_time>MINUTES_PER_DAY) 
  {
    station_trust--;
    return; 
  }

   /* compare to progress calculation */
  int candidate_progress_time=(((evaluation_time-candidate_sync_time+RDS_DERIVATION_TOLERANCE)/60000)+candidate_reference_time)%MINUTES_PER_DAY;
  
   #ifdef TRACE_CLOCK
      Serial.print(F("RDS:"));
      trace_printTime(measured_time);
   #endif
     
  if(measured_time==candidate_progress_time) { /* RDS delivered in expected range  */
      if(candidate_rds_trust<RDS_TRUST_GOOD) candidate_rds_trust+=1;
      candidate_sync_time=evaluation_time; 
      candidate_reference_time=measured_time; 
      if(station_trust<MAX_STATION_TRUST) station_trust++;   
      #ifdef TRACE_CLOCK
       Serial.print(F("\tgood"));
      #endif 

      if(candidate_rds_trust>=clock_rds_trust) // RDS has the better time, so take it
      {
        int sleepMinutesMemory;
        int intervalMinutesMemory;
        bool firstTimeSinceBoot=(clock_rds_trust<RDS_TRUST_ACCEPTABLE && candidate_rds_trust >=RDS_TRUST_ACCEPTABLE );
        if(clock_sleep_stop_time!=TRIGGER_IS_OFF) sleepMinutesMemory=clock_sleep_stop_time-clock_getCurrentTime(); /* Rescue Sleeptimer */
        if(clock_interval_alarm_time!=TRIGGER_IS_OFF) intervalMinutesMemory=clock_interval_alarm_time-clock_getCurrentTime(); /* Rescue Intervaltimer */
        clock_sync_time=candidate_sync_time;
        clock_reference_time=candidate_reference_time;
        clock_rds_trust=candidate_rds_trust;
        if(clock_sleep_stop_time!=TRIGGER_IS_OFF) clock_sleep_stop_time=(sleepMinutesMemory+clock_getCurrentTime()) % MINUTES_PER_DAY;
        if(clock_interval_alarm_time!=TRIGGER_IS_OFF) {
          clock_interval_alarm_time=(intervalMinutesMemory+clock_getCurrentTime()) % MINUTES_PER_DAY;
          storeSettings();
        }
        if(firstTimeSinceBoot && input_masterSwitchIsSet() 
             && (clock_reference_time>clock_alarm_time[0] && clock_reference_time<clock_alarm_time[0]+60)
             ) // First time after boot and alarm ad to be trigerred in the last hour
             {
             enter_STATE_WAKEUP();       
             #ifdef TRACE_CLOCK
                 Serial.println(F("!! Emergency Wakeup for Alarmtime during RDS time sync")); 
             #endif
             }
        #ifdef TRACE_CLOCK
          Serial.print(F("\tused by clock"));
        #endif 
      }
 
  } else {

     if(candidate_rds_trust>=RDS_TRUST_CANDIDATE) {
      candidate_rds_trust-=2; 
      #ifdef TRACE_CLOCK
       Serial.print(F("\treject"));
      #endif         
     } else  { /* Only, when our trust has gone , we try the new RDS value */
      station_trust--;
      candidate_sync_time=evaluation_time; 
      candidate_reference_time=measured_time;      
      candidate_rds_trust=0;
      #ifdef TRACE_CLOCK
       Serial.print(("\texchange"));
      #endif    
     }
  }
  
 #ifdef TRACE_CLOCK
    Serial.print(F("\tcandidate trust:"));
    Serial.print(candidate_rds_trust);
    Serial.print(F("\tclock trust:"));
    Serial.print(clock_rds_trust);
    Serial.print(F("\tstation trust:"));
    Serial.println(station_trust);
  #endif

}

void storeSettings() 
{
   struct clockSettingRecord current_settings;

  /* write settings to eeprom */
  current_settings.alarm_time=clock_alarm_time[0];
  current_settings.radio_preset=radio_getSelectedPreset();
  current_settings.interval_alarm_time=clock_interval_alarm_time;
  clockSettingsDB.updateRecord((byte*)(&current_settings));

}


/* ###########  Output helper ########## */

void callIdleScene(int minute_of_the_day, byte alarmIndicator)
{
  if(minute_of_the_day!=TIME_UNKNOWN) {
    output_renderClockScene((minute_of_the_day+PRESENTATION_SHIFT_MINUTES)%MINUTES_PER_DAY,alarmIndicator);
  }
  else output_renderTimeTrustScene();
}

void trace_printTime(int timeValue)
{
    Serial.print(timeValue/60);
    Serial.print(F(":"));
    Serial.print(timeValue%60);  
}


/* ************************************************************
 *    STATE functions
 * ************************************************************
 */

/* *************** STATE_IDLE ***************** */

void enter_STATE_IDLE(){
     clock_state=STATE_IDLE;
     callIdleScene(clock_getCurrentTime(),input_masterSwitchIsSet()?ALARM_INDICATOR_ON:ALARM_INDICATOR_OFF);
     #ifdef TRACE_CLOCK
     Serial.println(F("#IDLE"));
     #endif
}

void process_STATE_IDLE(){
 if(input_snoozeGotPressed()) {    
    enter_STATE_INTERVAL_SET();
    return;
  }
  
  if(input_hasEncoderChangeEvent()) {enter_STATE_ALARM_INFO();return;}
  if(input_selectGotPressed()) {enter_STATE_ALARM_CHANGE();return;}
 
  /* Check RDS Data when necessary */
  if(clock_getAgeOfReference()>REFERENCE_AGE_FOR_CHECK ||
     clock_rds_trust<RDS_TRUST_GOOD) {
     radio_setRdsScanActive(true);
     clock_evaluateRDSTime(radio_getLastRdsTimeInfo());
  }  else radio_setRdsScanActive(false);       

  callIdleScene(clock_getCurrentTime()
                             ,input_masterSwitchIsSet()?ALARM_INDICATOR_ON:ALARM_INDICATOR_OFF);  
}

/* *************** STATE_WAKEUP ***************** */

void enter_STATE_WAKEUP(){
   clock_state=STATE_WAKEUP;
   radio_fadeIn();
   clock_sleep_stop_time=TRIGGER_IS_OFF;
   clock_alarm_stop_time=clock_getCurrentTime()+ALARM_DURATION ;
   clock_interval_alarm_time=TRIGGER_IS_OFF;

   #ifdef TRACE_CLOCK
     Serial.println(F("#WAKEUP"));
   #endif
   callIdleScene(clock_getCurrentTime()
                               ,clock_interval_alarm_time==TRIGGER_IS_OFF?0:ALARM_INDICATOR_SNOOZE
                               |(input_masterSwitchIsSet()?ALARM_INDICATOR_ON :ALARM_INDICATOR_OFF));
}

void enter_STATE_WAKEUP_silentWithInterval(){
   clock_state=STATE_WAKEUP;
   clock_sleep_stop_time=TRIGGER_IS_OFF;
   clock_alarm_stop_time=clock_getCurrentTime()+ALARM_DURATION ;
   #ifdef TRACE_CLOCK
     Serial.println(F("#WAKEUP with interval"));
   #endif
}

void resume_STATE_WAKEUP(){
   clock_state=STATE_WAKEUP;
   clock_interval_alarm_time=TRIGGER_IS_OFF;
   clock_alarm_stop_time=clock_getCurrentTime()+ALARM_DURATION ;
   radio_fadeIn();
   #ifdef TRACE_CLOCK
     Serial.println(F(">WAKEUP"));
   #endif
}

void process_STATE_WAKEUP(){
  byte alarmIndicator=0;
  
  /* Snooze button */
  if(input_snoozeGotPressed()) {  
    clock_alarm_stop_time=(clock_getCurrentTime()+ALARM_DURATION+SNOOZE_DURATION)%MINUTES_PER_DAY ;   
    clock_interval_alarm_time=(clock_getCurrentTime()+SNOOZE_DURATION)%MINUTES_PER_DAY;
    radio_switchOff();
    output_sequence_acknowlegde();
   #ifdef TRACE_CLOCK
     Serial.print(F("WAKEUP:Snooze "));
     trace_printTime(clock_interval_alarm_time);
     Serial.println();
   #endif
    return;
  }

  /* Encoder turn or select button */
  if(input_hasEncoderChangeEvent()|| input_selectGotPressed()) {enter_STATE_STOP_PROCEDURE();return;}

  /* Manage output */
  if( clock_interval_alarm_time!=TRIGGER_IS_OFF) alarmIndicator|=ALARM_INDICATOR_SNOOZE;
  if(!input_masterSwitchIsSet()) alarmIndicator|=ALARM_INDICATOR_OFF;

  callIdleScene(clock_getCurrentTime()
                             ,alarmIndicator);

}

void exit_STATE_WAKEUP() {
   #ifdef TRACE_CLOCK
     Serial.println(F("<WAKEUP"));
   #endif
  radio_switchOff();
  clock_interval_alarm_time=TRIGGER_IS_OFF;
  clock_alarm_stop_time=TRIGGER_IS_OFF; 
  clock_sleep_stop_time=TRIGGER_IS_OFF; 
     storeSettings();
  if(clock_state==STATE_WAKEUP) enter_STATE_IDLE();
}

/* *************** STATE_STOP_PROCEDURE ***************** */

void enter_STATE_STOP_PROCEDURE(){
   clock_state=STATE_STOP_PROCEDURE;
   input_setEncoderRange(-20,20,1,20);  
   #ifdef TRACE_CLOCK
     Serial.println(F("#STOP_PROCEDURE"));
   #endif
   output_renderStopProcedureScene(input_getEncoderValue());
}


void process_STATE_STOP_PROCEDURE(){
 if(input_snoozeGotPressed()) {     
    #ifdef TRACE_CLOCK
     Serial.println(F("STOP_PROCEDURE:Snoozing"));
    #endif
    clock_alarm_stop_time=clock_getCurrentTime()+ALARM_DURATION ;  
    clock_interval_alarm_time=clock_getCurrentTime()+SNOOZE_DURATION;
    output_sequence_acknowlegde();
    radio_switchOff();
    resume_STATE_WAKEUP();
  }

  if(input_getEncoderValue()==0) {
    clock_last_wakeup_stop_millis=millis();
    output_sequence_acknowlegde();
    exit_STATE_WAKEUP();
    enter_STATE_IDLE();
    return;
  }

  if(input_getSecondsSinceLastEvent()> SECONDS_UNTIL_FALLBACK_SHORT)
  {
    resume_STATE_WAKEUP();
    return;
  }
  
  output_renderStopProcedureScene(input_getEncoderValue());
}

  


/* *************** STATE_ALARM_INFO ***************** */

void enter_STATE_ALARM_INFO(){
  
  clock_state=STATE_ALARM_INFO; 
  input_getEncoderValue(); // Read out Encoder to get of the last event 
  output_renderClockScene( clock_alarm_time[clock_focussed_alarmIndex],ALARM_INDICATOR_SHOW);
  #ifdef TRACE_CLOCK
         Serial.println(F("#ALARM_INFO"));
         trace_printTime( clock_alarm_time[clock_focussed_alarmIndex]);
         Serial.println();
  #endif
}

void process_STATE_ALARM_INFO(){
     if(input_snoozeGotPressed()
        || input_getSecondsSinceLastEvent()> SECONDS_UNTIL_FALLBACK_SHORT) {
            enter_STATE_IDLE(); return;
          }
    
    if(input_hasEncoderChangeEvent()) input_getEncoderValue(); 
    
    if(input_selectGotPressed()) {
             enter_STATE_ALARM_CHANGE();return;
             return;
    }
   output_renderClockScene( clock_alarm_time[clock_focussed_alarmIndex],ALARM_INDICATOR_SHOW);
  
}

/* *************** STATE_ALARM_CHANGE ***************** */

void enter_STATE_ALARM_CHANGE(){
  clock_state=STATE_ALARM_CHANGE; 
  input_setEncoderRange(0, MINUTES_PER_DAY-1,5,clock_alarm_time[clock_focussed_alarmIndex]);
  #ifdef DEBUG_HIGHRES_ALARMSET
    input_setEncoderRange(0, MINUTES_PER_DAY-1,1,clock_alarm_time[clock_focussed_alarmIndex]);
  #endif
  output_renderClockScene(input_getEncoderValue(),ALARM_INDICATOR_EDIT);
   #ifdef TRACE_CLOCK
         Serial.println(F("#ALARM_CHANGE"));
   #endif
}

void process_STATE_ALARM_CHANGE(){
      if(input_snoozeGotPressed() 
             ) {
             output_sequence_escape();
             enter_STATE_IDLE();return;
          }

      if(input_selectGotPressed()
      || input_getSecondsSinceLastEvent()> SECONDS_UNTIL_FALLBACK_LONG) {
        output_sequence_acknowlegde();
        clock_alarm_time[clock_focussed_alarmIndex]=input_getEncoderValue();
        storeSettings() ;
        enter_STATE_IDLE();return;       
      }

  #ifdef DEBUG_HIGHRES_ALARMSET
    if(input_hasEncoderChangeEvent()) {
      trace_printTime(input_getEncoderValue());
      Serial.println();
    }
  #endif
  
  output_renderClockScene(input_getEncoderValue(),ALARM_INDICATOR_EDIT); 
}


/* *************** STATE_INTERVAL_SET ***************** */

void enter_STATE_INTERVAL_SET(){
  clock_state=STATE_INTERVAL_SET; 
  int intervalMinutes=20;
  if(clock_sleep_stop_time!=TRIGGER_IS_OFF) intervalMinutes=-(clock_sleep_stop_time-clock_getCurrentTime());
  if(clock_interval_alarm_time!=TRIGGER_IS_OFF) intervalMinutes=clock_interval_alarm_time-clock_getCurrentTime();
  input_setEncoderRange(-60, 135,5,intervalMinutes); // 120+ for Setting Screens
  output_renderSleepScene(input_getEncoderValue());
  #ifdef TRACE_CLOCK
         Serial.println(F("#INTERVAL_SET"));
  #endif
}
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

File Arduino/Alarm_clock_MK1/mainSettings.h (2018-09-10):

//#define TRACE_ON 
//#define DEBUG

typedef  int MinutesOfDay_t;

/* Parameters for Display preferences */
#define MINUTE_FULL_CIRCLE_THRESHOLD 9  // Minute until we will show full circle
#define MINUTE_SHIFT_THRESHOLD 45        // Minute that will shift hour gap by 1 pixel
#define PRESENTATION_SHIFT_MINUTES  5 // Minutes, the whole presentation of the current time will be shiftet (+5 means, time will appear 5 Minutes early)

#define ALARM_DURATION  60  // Number of Minutes the Radio will play after last alarm trigger
#ifndef DEBUG
#define SNOOZE_DURATION 10   // Number of Minutes for the snooze time
#else
#define SNOOZE_DURATION 1   // #### DEBUG SETTING ####
#endif

#define DEFAULT_ALARM_TIME 6*60+30
//#define DEFAULT_ALARM_TIME 16*60+30    // Debug Wake time

#define SECONDS_UNTIL_FALLBACK_LONG 15   // Number of seconds the clock will wait before falling back 
#define SECONDS_UNTIL_FALLBACK_SHORT 5   // Number of seconds the clock will wait before falling back 


#define RADIO_PRESET_COUNT 4

/// The SI4703 board has to be connected by using the following connections:
/// | Arduino UNO pin    | Radio chip signal  | 
/// | -------------------| -------------------| 
/// | 3.3V (red)         | VCC                | 
/// | GND (black)        | GND                | 
/// | A5 or SCL (yellow) | SCLK               | 
/// | A4 or SDA (blue)   | SDIO               | 
/// | D2 (white)         | RST                |


/* Global necessary constants */

#define ALARM_INDICATOR_OFF  B00000001
#define ALARM_INDICATOR_EDIT B00000110
#define ALARM_INDICATOR_ON   B00000000
#define ALARM_INDICATOR_SHOW B00000010
#define ALARM_INDICATOR_SNOOZE  B10000000


/* Dont use the following outside Output, just placed here for convinience*/
#define ALARM_IDC_REMOVE_FROM_HOUR_MASK  B00000001
#define ALARM_IDC_SHOW_MASK              B00000010
#define ALARM_IDC_BLINK_MASK             B00000100

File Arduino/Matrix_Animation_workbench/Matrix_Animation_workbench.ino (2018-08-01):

//We always have to include the library
#include "LedControl.h"


#define TRACE_ON 1

#ifdef TRACE_ON
#define OUTPUT_TRACE 1
#define TRACE_CLOCK 1
#endif

#define LED8X8_DATAIN_PIN 12 
#define LED8X8_CLK_PIN 11 
#define LED8X8_LOAD_PIN 10 
#define LED8X8_COUNT 1
#define LED8X8_PANEL_0 0

#define MINUTE_SHIFT_THRESHOLD 45

#define FRAME_DELAY 750


enum MAIN_STATE {
  STATE_DEMO_CLOCK, 
  STATE_DEMO_RDS_TRUST_BAR,
  STATE_DEMO_ROTARY_TEST
};

MAIN_STATE main_state = STATE_DEMO_ROTARY_TEST; 


LedControl led8x8=LedControl(LED8X8_DATAIN_PIN,LED8X8_CLK_PIN,LED8X8_LOAD_PIN,LED8X8_COUNT);

/* we always wait a bit between updates of the display */
unsigned long delaytime=250;

#define MINUTE_FULL_CIRCLE_THRESHOLD 55
unsigned long clock_hour_bitmap=0xFFFFFFFF;
unsigned int clock_minute_bitmap=0xFFFF;



byte mirroredPattern (byte pattern)
{
  byte newPattern=0;
    newPattern|=pattern&B10000000; /* Copy highest bit */

  for(byte i=1;i<8;i++) {
    pattern<<=1;
    newPattern>>=1;
    newPattern|=pattern&B10000000; 
  }
  return newPattern;
}

void displayUpdate() {
  byte rowPattern;
  #ifdef OUTPUT_TRACE 
        Serial.println("-------");     
  #endif 
  for(int row=0;row<8;row++) {

    /* Add elemens of hour and minute bitmap to row pattern */
    /* map=0  H7  H6  H5  H4  H3  H2  H1  H0 
     *     1  H27                         H8
     *     2  H26     M3  M2  M1  M0      H9
     *     3  H25     M11         M4      H10
     *     4  H24     M10         M5      H11
     *     5  H23     M9  M8  M7  M6      H12
     *     6  H22                         H13
     *     7  H21 H20 H19 H18 H17 H16 H15 H14
     *     
     *     Minutt bits    = cba9876543210
     *     Minute bitmap  = 0110110110110
     *     Row target bit = _555432225432
     *     Row              _345555432222 
     *     row                   76543210        
     *     
    */
    switch(row) {
      case 0: rowPattern=mirroredPattern(clock_hour_bitmap); break;
      case 1: rowPattern=((clock_hour_bitmap>>20)&B10000000)|((clock_hour_bitmap>>8)&B00000001); break;
      case 2: rowPattern=((clock_hour_bitmap>>19)&B10000000)|((clock_hour_bitmap>>9)&B00000001)
                          | mirroredPattern((clock_minute_bitmap<<2)&B00111100); break;
      case 3: rowPattern=((clock_hour_bitmap>>18) & B10000000)|((clock_hour_bitmap>>10)&B00000001)
                          | ((clock_minute_bitmap>>2 & B00000100))
                          | ((clock_minute_bitmap>>6 & B00100000)); break;
      case 4: rowPattern=((clock_hour_bitmap>>17)&B10000000)|((clock_hour_bitmap>>11)&B00000001)
                          | ((clock_minute_bitmap>>3 & B00000100))
                          | ((clock_minute_bitmap>>5 & B00100000)); break;
      case 5: rowPattern=((clock_hour_bitmap>>16)&B10000000)|((clock_hour_bitmap>>12)&B00000001)
                          | ((clock_minute_bitmap>>4)&B00111100); break;
      case 6: rowPattern=((clock_hour_bitmap>>15)&B10000000)|((clock_hour_bitmap>>13)&B00000001); break;
      case 7: rowPattern=clock_hour_bitmap>>14;break;
      } // switch
   
    led8x8.setColumn(LED8X8_PANEL_0,7-row,rowPattern);   
    #ifdef OUTPUT_TRACE 
      Serial.println(rowPattern,BIN);
    #endif
  }
  #ifdef OUTPUT_TRACE 
    Serial.println("-------");       
  #endif 
}

void renderClockBitmaps(int minute_of_the_day) {

  unsigned int minute_of_the_hour = (minute_of_the_day%60);
  unsigned int hour = (minute_of_the_day/60)%12; /* will be truncated by integer arithmetic */
  unsigned int switchOffBar=0;
  unsigned long master_pattern=0;
  unsigned long simple_pattern=3;
  const unsigned long switchOffPattern=B01111110;

  #ifdef TRACE_CLOCK 
        Serial.print(hour);Serial.print(":");Serial.println(minute_of_the_hour);
  #endif 

  /* ********** *
   *   Hour
   * **********
   */
  simple_pattern<<=(2+hour*2); /* this will place hour 0 at bit 2 and 3, 1 at 4+5 and so on */
                                /* FEDCBA98 76543210 FEDCBA98 76543210 */
                                /* 00000000 00000000 00000000 00001100  = 0 Hrs */
                                /* 00000000 00000000 01100000 00000000  = 6 Hrs */
                                /* 00000011 00000000 00000000 00000000  = 11 Hrs */
                                /* ____aaaa ddddddcc ccccbbbb bbaaaa__  = simple pattern sides abcd*/

  if(minute_of_the_hour >= MINUTE_SHIFT_THRESHOLD) 
            simple_pattern<<=1; /* Shift the hole pattern to indicate upcoming hour */

  

  /* Add corner bits (+) to the pattern and overlay 11th to 1st hour */
  /*  ____aaaa ddddddcc ccccbbbb bbaaaaa_  => */
  /*  ____dddd dd+ccccc c+bbbbbb +aaaaaa+     */
  /*  84218421 84218421 84218421 84218421     */
  master_pattern=   ((simple_pattern & 0x0000003c)<<1)   /* -__aaaa- from 0 hr to 1 */
                  | ((simple_pattern & 0x0f000000)>>23)  /* -aaaa__- from 11 hr to 0 */       
                  | ((simple_pattern & 0x00000fc0)<<2)   /* -bbbbbb- from 2 hr to 4 */       
                  | ((simple_pattern & 0x0003f000)<<3)   /* -cccccc- from 5 hr to 7 */       
                  | ((simple_pattern & 0x00fc0000)<<4)   /* -dddddd- from 5 hr to 7 */       
                  | (((simple_pattern>>23)&(simple_pattern>>24)& 0x00000001)) /* left upper corner */       
                  | (((simple_pattern<<2) &(simple_pattern<<1)&  0x00000080))   /* Right upper corner */       
                  | (((simple_pattern<<3) &(simple_pattern<<2)&  0x00004000))   /* Right lower corner */       
                  | (((simple_pattern<<4) &(simple_pattern<<3)&  0x00200000)) ;  /* left lower corner */       


  switchOffBar=(((hour+1)/3)+2)%4;   /* Determine Side to set big bar */ 
  master_pattern |= switchOffPattern<<(switchOffBar*7);  

  /* write hour bitmap to final memory (Inverted to light up the zeroes) */
  clock_hour_bitmap=~master_pattern;

 
 #ifdef TRACE_CLOCK 
        Serial.println(0x80000000|simple_pattern,BIN);
        Serial.print(0x80000000|master_pattern,BIN);
  #endif    

  
   /* *************
    *    Minute
    * ************  */

                     
  simple_pattern=0x0db6;                                /* _24_ */                                                       /* 8  1 */                                                       /* 4  2 */
                                                        /* _18_ */
  if(minute_of_the_hour <MINUTE_FULL_CIRCLE_THRESHOLD) simple_pattern>>=(4-(minute_of_the_hour)/15)*3;
  /* move 12 o clock line to bit 0-3 */
  master_pattern=(simple_pattern<<3)|((simple_pattern>>9)&B00001111);
  
  clock_minute_bitmap=master_pattern;

  #ifdef TRACE_CLOCK 
        Serial.print("\t");
        Serial.println(0x8000|master_pattern,BIN);
  #endif
  
};
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

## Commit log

2018-07-27 Erstes Demo des Displays
2018-07-29 Timer counts by itself and only syncs sometime
2018-07-29 Integrated encoder to change a value (demo of Alarm time change)
2018-07-30 switched off debug code (rds time manipulation etc.)
2018-08-01 Added fritzing/alarmclock_mk1.fzz
    [alarmclock_mk1.fzz]
2018-08-01 Adapting encoder reading
2018-08-01 Workbench has reliable encoding and button reader (unsing timer 1 interrupt function)
2018-08-01 New Input module integrated into alarm clock (still has problems with bouncy snooze button)
    [input.ino]
2018-08-01 added test for snooze button
2018-08-01 Integrated master Button. Button Management complete.
2018-08-12 Volume 0 in RDS scan mode, first draft of pcb layout
    [alarmclock_mk1.fzz]
2018-08-13 Moved amplifier to pcb board
    [alarmclock_mk1.fzz]
2018-08-14 Added watchdog in the input interrupt to detect hanging system
2018-08-16 Watchdog using the timer für input scanning, resets system after 2 seconds without any input
    [Alarm_clock_MK1.ino, input.ino, radioReceiver.ino]
2018-08-16 Added main fitzing picture
    [alarmclock_mk1.fzz]
2018-08-16 documentation of physical prototype
2018-08-16 little changes
    [alarmclock_mk1.fzz]
2018-08-17 Added voltage regulator for amplifier
    [alarmclock_mk1.fzz]
2018-08-18 Moved all elements to final experimental pcb
    [alarmclock_mk1.fzz]
2018-08-19 Sleep Timer wird bei RDS korrekt weiter geführt
2018-08-19 Nap Timer added, Emergency procedures with pending alarm or nap timer after reboot.
    [Alarm_clock_MK1.ino, EepromDB.cpp, output.ino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]
2018-08-22 Started with blender model
    [model_mk2.blend]
2018-08-22 first model draft
    [model_mk2.blend]
2018-08-23 Worked on design
    [model_mk2.blend]
2018-08-25 refactored intervall wakeup (untested)
    [model_mk2.blend]
2018-08-26 Changed main size
    [model_mk2.blend]
2018-09-01 "Final" Design of case
    [model_mk2.blend]
2018-09-01 case Cutout layout
    [model_mk2.blend]
2018-09-04 Added Photoresistor to circuit
    [alarmclock_mk1.fzz]
2018-09-05 Version before Light sensor
2018-09-05 Added autoadjustment of led intensity to software
2018-09-09 copied manual de-en for translation
2018-09-09 updated png exports of fritzing/alarmclock_mk1
    [alarmclock_mk1.fzz]
2018-09-10 Set watchdog threshold to 4s (2s was to short for stable bootup) Switched trace off
    [Alarm_clock_MK1.ino, input.ino, mainSettings.h]
2018-09-10 Removed wrong nap timer handling from manuals
